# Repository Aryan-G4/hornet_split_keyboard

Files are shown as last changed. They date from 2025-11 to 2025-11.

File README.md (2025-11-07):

# Hornet Keyboard — Split Wireless Communication and Charging Mechanical Keyboard PCB

The Hornet Keyboard is the *first* fully custom, split, mechanical keyboard featuring integrated **Bluetooth**, **Qi wireless charging** on either split, and optional **USB-C programmability/Connectivity**.  
This project represents a complete end-to-end embedded hardware design — from schematic capture to multi-layer PCB layout — optimized for both performance and manufacturability.


---

## Project Overview

| Feature | Description |
|---|---|
| **Form Factor** | Compact Split ergonomic layout key matrix |
| **Microcontroller** | Industry standard NRF52840 QIAA semi-BGA |
| **MCU Interface** | USB-C (DFU bootloader + HID communication) and STLinkV3 SWD |
| **Wireless** | On-board Bluetooth LE trace antenna with matched RF trace and controlled impedance |
| **Power** | Dual power paths: 3.7 V LiPo battery or USB VBUS (5 V) with power switching (USB PRIORITY)|
| **Charging Options** | USB-C Power Delivery (5V @ 1000mA) or Qi wireless charging receiver (5V @ 800mA)|
| **Firmware** | DFU-based update over USB; designed for ZMK and QMK-style firmware structure |
| **Sensors** | On-board voltage monitoring and NTC-based battery temperature protection |
| **Other** | Rotary encoders, Jumpers to probe and enable/disable submodules | standardized M3 mounting holes |
---
## Schematics




## Layout

3D model (ish)

hornet_kb_jlcpcb_render

Individual Layers:
L1: FCu

L2: In1

L3: In2

L4: BCu


## System Architecture

The system integrates three major electrical domains:

1. **Digital Domain (nRF52840)**
   - Industry standard MCU with built-in BLE 5.4
   - High-speed interrupt-based matrix scanning and battery management.
   - Dedicated power pin for reading battery charge.

2. **Power Management Domain**
   - Dual-source power path with **ideal diode OR-ing** between USB VBUS and LiPo battery.
   - **Li-Ion charge controller** managing both USB and Qi charge inputs.
   - **Dynamic load sharing** ensures stable operation while charging.
   - **Overcurrent and thermal protection** via FET-based switching and NTC feedback.

3. **Wireless RF Domain**
   - Custom-routed **50 Ω matched trace** for the Bluetooth antenna.
   - π-matching network for impedance tuning based on antenna manufacturer data.
   - Keepout and ground clearance zone designed per RF layout guidelines.

---

## Electrical Design Highlights

- **4-layer PCB** for clean separation of signal, power, and RF planes.
- **Differential USB data routing** (D+ / D–) with 90 Ω differential impedance.
- **Common-mode choke** and ESD suppression on USB-C connector for EMI resilience.
- **Reverse-current blocking MOSFET** for power path control between USB and battery.
- **Qi receiver integration** including rectification, voltage regulation, and charge negotiation.
- **Seamless transition** between wireless power and USB without brownout.

## Tools and Workflow

- **KiCad 8.0** — schematic capture and PCB design  
- **JLCPCB / LCSC** — fabrication and component sourcing  
- **SolidWorks** — mechanical fit and case alignment  
- **ZMK** - Open source repo for wireless split keyboards
- **DFU-util** — firmware flashing over USB-C and SWD through my STLinkV3

---

## Firmware Architecture 
- Utilize USBC's DFU to flash all firmware and STLinkV3 to flash in case of USBC fail
- Implement ZMK- wireless open source keyboard firmware kit for wireless split keyboards
- Implement QMK alternatively, for wired keyboards
- Eventually write my own firmware, optimizing speed and runtime.

---

---

## Gallery and work in progress photos :D










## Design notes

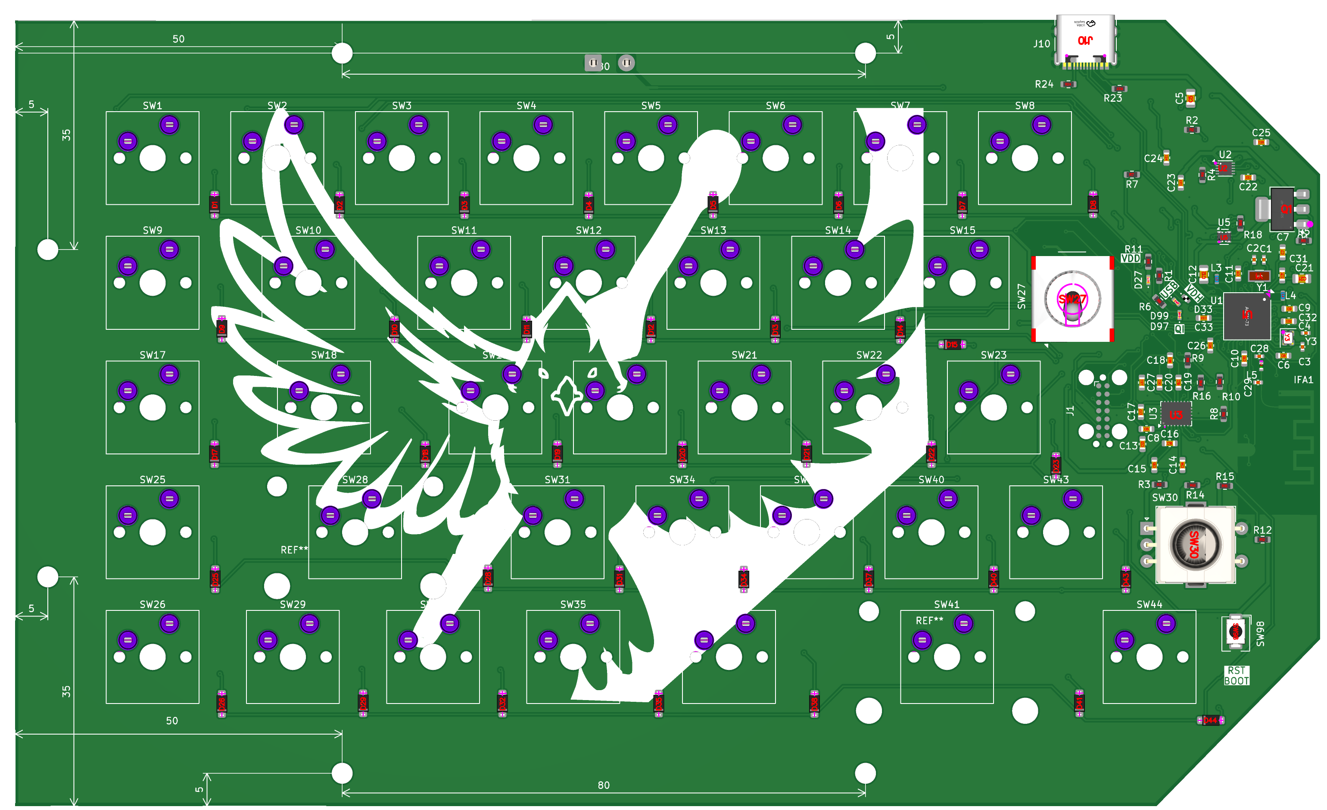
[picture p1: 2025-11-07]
hornet_kb_jlcpcb_render.png

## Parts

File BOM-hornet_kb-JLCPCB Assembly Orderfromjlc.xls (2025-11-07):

JLCPCB BOM Tool - BOM Matching
BOM name：BOM-hornet_kb-JLCPCB Assembly Order.xlsx |  |  | Download Time：2025-10-26 09:23:43 |  |  |  | * Our matching results are updated in real-time, but stock and prices may change. If it's been over 24 hours, please re-match before placing your order.
PCB Assembled Qty：5 |  |  | Est. Total Price：134.5413
Your BOM |  |  |  |  | Matched Parts |  |  |  |  |  |  | Order Information
Top Designator | Bottom Designator | Comment | Footprint | JLCPCB Part # | Matches | Part # | Manufacturer | Footprint | Description | Category | Warning | JLCPCB Part # | Product link | Lib Type | Qty | Source | Total Price ($)
C1 |  | 12p | C_0402_1005Metric |  | Select by Customer | 0402CG120J500NT | FH (Guangdong Fenghua Advanced Tech) | 0402 | 12pF 50V C0G ±5% 0402 Multilayer Ceramic Capacitors MLCC - SMD/SMT ROHS | Multilayer Ceramic Capacitors MLCC - SMD/SMT | 1.The comment (0402CG120J500NT) of this part does not match the one (12p) provided in your BOM. Please confirm; | C1547 | https://jlcpcb.com/partdetail/1899-0402CG120J500NT/C1547 | Basic | 20 | 20 JLCPCB | 0.022
C2 |  | 12p | C_0402_1005Metric |  | Select by Customer | 0402CG120J500NT | FH (Guangdong Fenghua Advanced Tech) | 0402 | 12pF 50V C0G ±5% 0402 Multilayer Ceramic Capacitors MLCC - SMD/SMT ROHS | Multilayer Ceramic Capacitors MLCC - SMD/SMT | 1.The comment (0402CG120J500NT) of this part does not match the one (12p) provided in your BOM. Please confirm; | C1547 | https://jlcpcb.com/partdetail/1899-0402CG120J500NT/C1547 | Basic | 20 | 20 JLCPCB | 0.022
C3 |  | 12p | C_0402_1005Metric |  | Select by Customer | 0402CG120J500NT | FH (Guangdong Fenghua Advanced Tech) | 0402 | 12pF 50V C0G ±5% 0402 Multilayer Ceramic Capacitors MLCC - SMD/SMT ROHS | Multilayer Ceramic Capacitors MLCC - SMD/SMT | 1.The comment (0402CG120J500NT) of this part does not match the one (12p) provided in your BOM. Please confirm; | C1547 | https://jlcpcb.com/partdetail/1899-0402CG120J500NT/C1547 | Basic | 20 | 20 JLCPCB | 0.022
C4 |  | 12p | C_0402_1005Metric |  | Select by Customer | 0402CG120J500NT | FH (Guangdong Fenghua Advanced Tech) | 0402 | 12pF 50V C0G ±5% 0402 Multilayer Ceramic Capacitors MLCC - SMD/SMT ROHS | Multilayer Ceramic Capacitors MLCC - SMD/SMT | 1.The comment (0402CG120J500NT) of this part does not match the one (12p) provided in your BOM. Please confirm; | C1547 | https://jlcpcb.com/partdetail/1899-0402CG120J500NT/C1547 | Basic | 20 | 20 JLCPCB | 0.022
C5 |  | 4.7u | C_0805_2012Metric |  | Unconfirmed | CL21A475KAQNNNE | Samsung Electro-Mechanics | 0805 | 25V 4.7uF X5R ±10% 0805 Multilayer Ceramic Capacitors MLCC - SMD/SMT ROHS | Multilayer Ceramic Capacitors MLCC - SMD/SMT | 1.The comment (CL21A475KAQNNNE) of this part does not match the one (4.7u) provided in your BOM. Please confirm; | C1779 | https://jlcpcb.com/partdetail/2131-CL21A475KAQNNNE/C1779 | Basic | 20 | 20 JLCPCB | 0.238
C12 |  | 4.7u | C_0805_2012Metric |  | Unconfirmed | CL21A475KAQNNNE | Samsung Electro-Mechanics | 0805 | 25V 4.7uF X5R ±10% 0805 Multilayer Ceramic Capacitors MLCC - SMD/SMT ROHS | Multilayer Ceramic Capacitors MLCC - SMD/SMT | 1.The comment (CL21A475KAQNNNE) of this part does not match the one (4.7u) provided in your BOM. Please confirm; | C1779 | https://jlcpcb.com/partdetail/2131-CL21A475KAQNNNE/C1779 | Basic | 20 | 20 JLCPCB | 0.238
C21 |  | 4.7u | C_0805_2012Metric |  | Unconfirmed | CL21A475KAQNNNE | Samsung Electro-Mechanics | 0805 | 25V 4.7uF X5R ±10% 0805 Multilayer Ceramic Capacitors MLCC - SMD/SMT ROHS | Multilayer Ceramic Capacitors MLCC - SMD/SMT | 1.The comment (CL21A475KAQNNNE) of this part does not match the one (4.7u) provided in your BOM. Please confirm; | C1779 | https://jlcpcb.com/partdetail/2131-CL21A475KAQNNNE/C1779 | Basic | 20 | 20 JLCPCB | 0.238
C6 |  | 100p | C_0603_1608Metric |  | Unconfirmed | CL10C101JB8NNNC | Samsung Electro-Mechanics | 0603 | 100pF 50V C0G ±5% 0603 Multilayer Ceramic Capacitors MLCC - SMD/SMT ROHS | Multilayer Ceramic Capacitors MLCC - SMD/SMT | 1.The comment (CL10C101JB8NNNC) of this part does not match the one (100p) provided in your BOM. Please confirm; | C14858 | https://jlcpcb.com/partdetail/15530-CL10C101JB8NNNC/C14858 | Basic | 24 | 24 JLCPCB | 0.0744
C8 |  | 100p | C_0603_1608Metric |  | Unconfirmed | CL10C101JB8NNNC | Samsung Electro-Mechanics | 0603 | 100pF 50V C0G ±5% 0603 Multilayer Ceramic Capacitors MLCC - SMD/SMT ROHS | Multilayer Ceramic Capacitors MLCC - SMD/SMT | 1.The comment (CL10C101JB8NNNC) of this part does not match the one (100p) provided in your BOM. Please confirm; | C14858 | https://jlcpcb.com/partdetail/15530-CL10C101JB8NNNC/C14858 | Basic | 24 | 24 JLCPCB | 0.0744
C11 |  | 100p | C_0603_1608Metric |  | Unconfirmed | CL10C101JB8NNNC | Samsung Electro-Mechanics | 0603 | 100pF 50V C0G ±5% 0603 Multilayer Ceramic Capacitors MLCC - SMD/SMT ROHS | Multilayer Ceramic Capacitors MLCC - SMD/SMT | 1.The comment (CL10C101JB8NNNC) of this part does not match the one (100p) provided in your BOM. Please confirm; | C14858 | https://jlcpcb.com/partdetail/15530-CL10C101JB8NNNC/C14858 | Basic | 24 | 24 JLCPCB | 0.0744
C26 |  | 100p | C_0603_1608Metric |  | Unconfirmed | CL10C101JB8NNNC | Samsung Electro-Mechanics | 0603 | 100pF 50V C0G ±5% 0603 Multilayer Ceramic Capacitors MLCC - SMD/SMT ROHS | Multilayer Ceramic Capacitors MLCC - SMD/SMT | 1.The comment (CL10C101JB8NNNC) of this part does not match the one (100p) provided in your BOM. Please confirm; | C14858 | https://jlcpcb.com/partdetail/15530-CL10C101JB8NNNC/C14858 | Basic | 24 | 24 JLCPCB | 0.0744
C31 |  | 100p | C_0603_1608Metric |  | Unconfirmed | CL10C101JB8NNNC | Samsung Electro-Mechanics | 0603 | 100pF 50V C0G ±5% 0603 Multilayer Ceramic Capacitors MLCC - SMD/SMT ROHS | Multilayer Ceramic Capacitors MLCC - SMD/SMT | 1.The comment (CL10C101JB8NNNC) of this part does not match the one (100p) provided in your BOM. Please confirm; | C14858 | https://jlcpcb.com/partdetail/15530-CL10C101JB8NNNC/C14858 | Basic | 24 | 24 JLCPCB | 0.0744
C32 |  | 100p | C_0603_1608Metric |  | Unconfirmed | CL10C101JB8NNNC | Samsung Electro-Mechanics | 0603 | 100pF 50V C0G ±5% 0603 Multilayer Ceramic Capacitors MLCC - SMD/SMT ROHS | Multilayer Ceramic Capacitors MLCC - SMD/SMT | 1.The comment (CL10C101JB8NNNC) of this part does not match the one (100p) provided in your BOM. Please confirm; | C14858 | https://jlcpcb.com/partdetail/15530-CL10C101JB8NNNC/C14858 | Basic | 24 | 24 JLCPCB | 0.0744
C33 |  | 100p | C_0603_1608Metric |  | Unconfirmed | CL10C101JB8NNNC | Samsung Electro-Mechanics | 0603 | 100pF 50V C0G ±5% 0603 Multilayer Ceramic Capacitors MLCC - SMD/SMT ROHS | Multilayer Ceramic Capacitors MLCC - SMD/SMT | 1.The comment (CL10C101JB8NNNC) of this part does not match the one (100p) provided in your BOM. Please confirm; | C14858 | https://jlcpcb.com/partdetail/15530-CL10C101JB8NNNC/C14858 | Basic | 24 | 24 JLCPCB | 0.0744
C7 |  | 100n | C_0603_1608Metric |  | Unconfirmed | CC0603KRX7R9BB104 | YAGEO | 0603 | 100nF 50V X7R ±10% 0603 Multilayer Ceramic Capacitors MLCC - SMD/SMT ROHS | Multilayer Ceramic Capacitors MLCC - SMD/SMT | 1.The comment (CC0603KRX7R9BB104) of this part does not match the one (100n) provided in your BOM. Please confirm; | C14663 | https://jlcpcb.com/partdetail/YAGEO-CC0603KRX7R9BB104/C14663 | Basic | 20 | 20 JLCPCB | 0.048
C9 |  | 1u | C_0603_1608Metric |  | Unconfirmed | CL10A105KB8NNNC | Samsung Electro-Mechanics | 0603 | 1uF 50V X5R ±10% 0603 Multilayer Ceramic Capacitors MLCC - SMD/SMT ROHS | Multilayer Ceramic Capacitors MLCC - SMD/SMT | 1.The comment (CL10A105KB8NNNC) of this part does not match the one (1u) provided in your BOM. Please confirm; | C15849 | https://jlcpcb.com/partdetail/16531-CL10A105KB8NNNC/C15849 | Basic | 20 | 20 JLCPCB | 0.094
C22 |  | 1u | C_0603_1608Metric |  | Unconfirmed | CL10A105KB8NNNC | Samsung Electro-Mechanics | 0603 | 1uF 50V X5R ±10% 0603 Multilayer Ceramic Capacitors MLCC - SMD/SMT ROHS | Multilayer Ceramic Capacitors MLCC - SMD/SMT | 1.The comment (CL10A105KB8NNNC) of this part does not match the one (1u) provided in your BOM. Please confirm; | C15849 | https://jlcpcb.com/partdetail/16531-CL10A105KB8NNNC/C15849 | Basic | 20 | 20 JLCPCB | 0.094
C23 |  | 1u | C_0603_1608Metric |  | Unconfirmed | CL10A105KB8NNNC | Samsung Electro-Mechanics | 0603 | 1uF 50V X5R ±10% 0603 Multilayer Ceramic Capacitors MLCC - SMD/SMT ROHS | Multilayer Ceramic Capacitors MLCC - SMD/SMT | 1.The comment (CL10A105KB8NNNC) of this part does not match the one (1u) provided in your BOM. Please confirm; | C15849 | https://jlcpcb.com/partdetail/16531-CL10A105KB8NNNC/C15849 | Basic | 20 | 20 JLCPCB | 0.094
C10 |  | 820p | C_0603_1608Metric |  | Unconfirmed | CC0603JRNPO9BN821 | YAGEO | 0603 | 50V 820pF NP0 ±5% 0603 Multilayer Ceramic Capacitors MLCC - SMD/SMT ROHS | Multilayer Ceramic Capacitors MLCC - SMD/SMT | 1.The comment (CC0603JRNPO9BN821) of this part does not match the one (820p) provided in your BOM. Please confirm; | C107057 | https://jlcpcb.com/partdetail/YAGEO-CC0603JRNPO9BN821/C107057 | Extended | 20 | 20 JLCPCB | 0.082
C13 |  | 200n | C_0603_1608Metric |  | Select by Customer | GZ1608D601TF | Sunlord | 0603 | -55℃~+125℃ 1 200mA 450mΩ 600Ω@100MHz ±25% 0603 Ferrite Beads ROHS | Ferrite Beads | 1.The comment (GZ1608D601TF) of this part does not match the one (200n) provided in your BOM. Please confirm; | C1002 | https://jlcpcb.com/partdetail/Sunlord-GZ1608D601TF/C1002 | Basic | 20 | 20 JLCPCB | 0.132
C14 |  | 22n | C_0603_1608Metric |  | Unconfirmed | CL10B223KB8NNNC | Samsung Electro-Mechanics | 0603 | 22nF 50V X7R ±10% 0603 Multilayer Ceramic Capacitors MLCC - SMD/SMT ROHS | Multilayer Ceramic Capacitors MLCC - SMD/SMT | 1.The comment (CL10B223KB8NNNC) of this part does not match the one (22n) provided in your BOM. Please confirm; | C21122 | https://jlcpcb.com/partdetail/21834-CL10B223KB8NNNC/C21122 | Basic | 20 | 20 JLCPCB | 0.078
C19 |  | 22n | C_0603_1608Metric |  | Unconfirmed | CL10B223KB8NNNC | Samsung Electro-Mechanics | 0603 | 22nF 50V X7R ±10% 0603 Multilayer Ceramic Capacitors MLCC - SMD/SMT ROHS | Multilayer Ceramic Capacitors MLCC - SMD/SMT | 1.The comment (CL10B223KB8NNNC) of this part does not match the one (22n) provided in your BOM. Please confirm; | C21122 | https://jlcpcb.com/partdetail/21834-CL10B223KB8NNNC/C21122 | Basic | 20 | 20 JLCPCB | 0.078
C15 |  | 10n | C_0603_1608Metric |  | Unconfirmed | 0603B103K500NT | FH (Guangdong Fenghua Advanced Tech) | 0603 | 10nF 50V X7R ±10% 0603 Multilayer Ceramic Capacitors MLCC - SMD/SMT ROHS | Multilayer Ceramic Capacitors MLCC - SMD/SMT | 1.The comment (0603B103K500NT) of this part does not match the one (10n) provided in your BOM. Please confirm; | C57112 | https://jlcpcb.com/partdetail/58143-0603B103K500NT/C57112 | Basic | 20 | 20 JLCPCB | 0.048
C20 |  | 10n | C_0603_1608Metric |  | Unconfirmed | 0603B103K500NT | FH (Guangdong Fenghua Advanced Tech) | 0603 | 10nF 50V X7R ±10% 0603 Multilayer Ceramic Capacitors MLCC - SMD/SMT ROHS | Multilayer Ceramic Capacitors MLCC - SMD/SMT | 1.The comment (0603B103K500NT) of this part does not match the one (10n) provided in your BOM. Please confirm; | C57112 | https://jlcpcb.com/partdetail/58143-0603B103K500NT/C57112 | Basic | 20 | 20 JLCPCB | 0.048
C16 |  | 470p | C_0603_1608Metric |  | Unconfirmed | 0603B471K500NT | FH (Guangdong Fenghua Advanced Tech) | 0603 | 470pF 50V X7R ±10% 0603 Multilayer Ceramic Capacitors MLCC - SMD/SMT ROHS | Multilayer Ceramic Capacitors MLCC - SMD/SMT | 1.The comment (0603B471K500NT) of this part does not match the one (470p) provided in your BOM. Please confirm; | C1620 | https://jlcpcb.com/partdetail/1972-0603B471K500NT/C1620 | Basic | 20 | 20 JLCPCB | 0.054
C18 |  | 470p | C_0603_1608Metric |  | Unconfirmed | 0603B471K500NT | FH (Guangdong Fenghua Advanced Tech) | 0603 | 470pF 50V X7R ±10% 0603 Multilayer Ceramic Capacitors MLCC - SMD/SMT ROHS | Multilayer Ceramic Capacitors MLCC - SMD/SMT | 1.The comment (0603B471K500NT) of this part does not match the one (470p) provided in your BOM. Please confirm; | C1620 | https://jlcpcb.com/partdetail/1972-0603B471K500NT/C1620 | Basic | 20 | 20 JLCPCB | 0.054
C17 |  | 2.2n | C_0603_1608Metric |  | Unconfirmed | 0603B222K500NT | FH (Guangdong Fenghua Advanced Tech) | 0603 | 2.2nF 50V X7R ±10% 0603 Multilayer Ceramic Capacitors MLCC - SMD/SMT ROHS | Multilayer Ceramic Capacitors MLCC - SMD/SMT | 1.The comment (0603B222K500NT) of this part does not match the one (2.2n) provided in your BOM. Please confirm; | C1604 | https://jlcpcb.com/partdetail/1956-0603B222K500NT/C1604 | Basic | 20 | 20 JLCPCB | 0.054
C24 |  | 10u | C_0603_1608Metric |  | Unconfirmed | CL10A106KP8NNNC | Samsung Electro-Mechanics | 0603 | 10V 10uF X5R ±10% 0603 Multilayer Ceramic Capacitors MLCC - SMD/SMT ROHS | Multilayer Ceramic Capacitors MLCC - SMD/SMT | 1.The comment (CL10A106KP8NNNC) of this part does not match the one (10u) provided in your BOM. Please confirm; | C19702 | https://jlcpcb.com/partdetail/20411-CL10A106KP8NNNC/C19702 | Basic | 20 | 20 JLCPCB | 0.112
C25 |  | 10u | C_0603_1608Metric |  | Unconfirmed | CL10A106KP8NNNC | Samsung Electro-Mechanics | 0603 | 10V 10uF X5R ±10% 0603 Multilayer Ceramic Capacitors MLCC - SMD/SMT ROHS | Multilayer Ceramic Capacitors MLCC - SMD/SMT | 1.The comment (CL10A106KP8NNNC) of this part does not match the one (10u) provided in your BOM. Please confirm; | C19702 | https://jlcpcb.com/partdetail/20411-CL10A106KP8NNNC/C19702 | Basic | 20 | 20 JLCPCB | 0.112
C27 |  | 4.7u | C_0603_1608Metric |  | Unconfirmed | CL10A475KO8NNNC | Samsung Electro-Mechanics | 0603 | 16V 4.7uF X5R ±10% 0603 Multilayer Ceramic Capacitors MLCC - SMD/SMT ROHS | Multilayer Ceramic Capacitors MLCC - SMD/SMT | 1.The comment (CL10A475KO8NNNC) of this part does not match the one (4.7u) provided in your BOM. Please confirm; | C19666 | https://jlcpcb.com/partdetail/20375-CL10A475KO8NNNC/C19666 | Basic | 20 | 20 JLCPCB | 0.184
C28 |  | 1p | C_0402_1005Metric |  | Select by Customer | 0402CG1R0C500NT | FH (Guangdong Fenghua Advanced Tech) | 0402 | 1pF 50V C0G 0402 Multilayer Ceramic Capacitors MLCC - SMD/SMT ROHS | Multilayer Ceramic Capacitors MLCC - SMD/SMT | 1.The comment (0402CG1R0C500NT) of this part does not match the one (1p) provided in your BOM. Please confirm; | C1550 | https://jlcpcb.com/partdetail/1902-0402CG1R0C500NT/C1550 | Extended | 20 | 20 JLCPCB | 0.022
C29 |  | 1p | C_0402_1005Metric |  | Select by Customer | 0402CG1R0C500NT | FH (Guangdong Fenghua Advanced Tech) | 0402 | 1pF 50V C0G 0402 Multilayer Ceramic Capacitors MLCC - SMD/SMT ROHS | Multilayer Ceramic Capacitors MLCC - SMD/SMT | 1.The comment (0402CG1R0C500NT) of this part does not match the one (1p) provided in your BOM. Please confirm; | C1550 | https://jlcpcb.com/partdetail/1902-0402CG1R0C500NT/C1550 | Extended | 20 | 20 JLCPCB | 0.022
D1 |  | ESC | Diode_SOD-123 |  | Unconfirmed | 1N4148W | JSMSEMI | SOD-123 | -55℃~+150℃@(Tj) 1.25V@150mA 100V 1uA@75V 300mA 400mW 4A 8ns Independent SOD-123 Switching Diodes ROHS | Switching Diodes | 1.Multiple lines in the BOM have been matched to the same part. Please check if the matching is correct. ; | C917030 | https://jlcpcb.com/partdetail/JSMSEMI-1N4148W/C917030 | Extended | 84 | 84 JLCPCB | 0.4452
D2 |  | ~/` | Diode_SOD-123 |  | Unconfirmed | 1N4148W | JSMSEMI | SOD-123 | -55℃~+150℃@(Tj) 1.25V@150mA 100V 1uA@75V 300mA 400mW 4A 8ns Independent SOD-123 Switching Diodes ROHS | Switching Diodes | 1.Multiple lines in the BOM have been matched to the same part. Please check if the matching is correct. ; | C917030 | https://jlcpcb.com/partdetail/JSMSEMI-1N4148W/C917030 | Extended | 84 | 84 JLCPCB | 0.4452
D3 |  | 1 | Diode_SOD-123 |  | Unconfirmed | 1N4148W | JSMSEMI | SOD-123 | -55℃~+150℃@(Tj) 1.25V@150mA 100V 1uA@75V 300mA 400mW 4A 8ns Independent SOD-123 Switching Diodes ROHS | Switching Diodes | 1.Multiple lines in the BOM have been matched to the same part. Please check if the matching is correct. ; | C917030 | https://jlcpcb.com/partdetail/JSMSEMI-1N4148W/C917030 | Extended | 84 | 84 JLCPCB | 0.4452
D4 |  | 2 | Diode_SOD-123 |  | Unconfirmed | 1N4148W | JSMSEMI | SOD-123 | -55℃~+150℃@(Tj) 1.25V@150mA 100V 1uA@75V 300mA 400mW 4A 8ns Independent SOD-123 Switching Diodes ROHS | Switching Diodes | 1.Multiple lines in the BOM have been matched to the same part. Please check if the matching is correct. ; | C917030 | https://jlcpcb.com/partdetail/JSMSEMI-1N4148W/C917030 | Extended | 84 | 84 JLCPCB | 0.4452
D5 |  | 3 | Diode_SOD-123 |  | Unconfirmed | 1N4148W | JSMSEMI | SOD-123 | -55℃~+150℃@(Tj) 1.25V@150mA 100V 1uA@75V 300mA 400mW 4A 8ns Independent SOD-123 Switching Diodes ROHS | Switching Diodes | 1.Multiple lines in the BOM have been matched to the same part. Please check if the matching is correct. ; | C917030 | https://jlcpcb.com/partdetail/JSMSEMI-1N4148W/C917030 | Extended | 84 | 84 JLCPCB | 0.4452
D6 |  | 4 | Diode_SOD-123 |  | Unconfirmed | 1N4148W | JSMSEMI | SOD-123 | -55℃~+150℃@(Tj) 1.25V@150mA 100V 1uA@75V 300mA 400mW 4A 8ns Independent SOD-123 Switching Diodes ROHS | Switching Diodes | 1.Multiple lines in the BOM have been matched to the same part. Please check if the matching is correct. ; | C917030 | https://jlcpcb.com/partdetail/JSMSEMI-1N4148W/C917030 | Extended | 84 | 84 JLCPCB | 0.4452
D7 |  | 5 | Diode_SOD-123 |  | Unconfirmed | 1N4148W | JSMSEMI | SOD-123 | -55℃~+150℃@(Tj) 1.25V@150mA 100V 1uA@75V 300mA 400mW 4A 8ns Independent SOD-123 Switching Diodes ROHS | Switching Diodes | 1.Multiple lines in the BOM have been matched to the same part. Please check if the matching is correct. ; | C917030 | https://jlcpcb.com/partdetail/JSMSEMI-1N4148W/C917030 | Extended | 84 | 84 JLCPCB | 0.4452
D8 |  | 6 | Diode_SOD-123 |  | Unconfirmed | 1N4148W | JSMSEMI | SOD-123 | -55℃~+150℃@(Tj) 1.25V@150mA 100V 1uA@75V 300mA 400mW 4A 8ns Independent SOD-123 Switching Diodes ROHS | Switching Diodes | 1.Multiple lines in the BOM have been matched to the same part. Please check if the matching is correct. ; | C917030 | https://jlcpcb.com/partdetail/JSMSEMI-1N4148W/C917030 | Extended | 84 | 84 JLCPCB | 0.4452
D10,D11,D12,D13,D14,D15,D17,D18,D19,D20,D21,D22,D23,D25,D26,D28,D29,D31,D32,D34,D35,D37,D38,D40,D41,D43,D44,D9 |  | D | Diode_SOD-123 |  | Unconfirmed | 1N4148W | JSMSEMI | SOD-123 | -55℃~+150℃@(Tj) 1.25V@150mA 100V 1uA@75V 300mA 400mW 4A 8ns Independent SOD-123 Switching Diodes ROHS | Switching Diodes | 1.Multiple lines in the BOM have been matched to the same part. Please check if the matching is correct. ; | C917030 | https://jlcpcb.com/partdetail/JSMSEMI-1N4148W/C917030 | Extended | 84 | 84 JLCPCB | 0.4452
D27 |  | VDD | LED_0402_1005Metric |  | Select by System | YLED0402B | YONGYUTAI | 0402 | -40℃~+85℃ 100mW 100mcd 120° 2.6V~3.1V 20mA 460nm~475nm 469nm Blue Water Clear 0402 LED Indication - Discrete ROHS | LED Indication - Discrete |  | C30584803 | https://jlcpcb.com/partdetail/YONGYUTAI-YLED0402B/C30584803 | Extended | 20 | 20 JLCPCB | 0.252
D33 |  | LED | LED_0402_1005Metric |  | Select by Customer | YLED0402O | YONGYUTAI | 0402 | -40℃~+85℃ 1.8V~2.3V 120° 20mA 210mcd 48mW 598nm~608nm 611nm Orange Water Clear 0402 LED Indication - Discrete ROHS | LED Indication - Discrete | 1.The comment (YLED0402O) of this part does not match the one (LED) provided in your BOM. Please confirm; | C28310436 | https://jlcpcb.com/partdetail/YONGYUTAI-YLED0402O/C28310436 | Extended | 20 | 20 JLCPCB | 0.152
D97 |  | USB_CHG | LED_0402_1005Metric |  | Select by Customer | 16-213SDRC/S530-A3/TR8 | Everlight Elec | 0402 | 120° 20mA 2V 43mcd 639nm 650nm Red Water Clear 0402 LED Indication - Discrete ROHS | LED Indication - Discrete |  | C71911 | https://jlcpcb.com/partdetail/EverlightElec-16_213SDRC_S530_A3TR8/C71911 | Extended | 7 | 7 JLCPCB | 0.2114
D99 |  | QI_CHG | LED_0402_1005Metric |  | Select by Customer | 16-213/GHC-YR1S1/3T | Everlight Elec | 0402 | -40℃~+85℃ 110mW 120° 20mA 518nm 520nm~535nm Emerald Green Water Clear 0402 LED Indication - Discrete ROHS | LED Indication - Discrete |  | C74338 | https://jlcpcb.com/partdetail/EverlightElec-16_213_GHC_YR1S13T/C74338 | Extended | 7 | 7 JLCPCB | 0.3486
 | J2 | Conn_01x03 | JST_GH_SM03B-GHS-TB_1x03-1MP_P1.25mm_Horizontal |  | Select by System | SM03B-GHS-TB(LF)(SN) | JST | SMD,P=1.25mm,卧贴 | -25℃~+85℃ 1 1.25mm 1A 1x3P 3 3P 4.13mm 4.25mm 50V 7mm Auxiliary Solder Pin GH PA9T Phosphor Bronze Surface Mount, Right Angle Tin UL94V-0 White SMD,P=1.25mm,Surface Mount，Right Angle Wire To Board Connector ROHS | Wire To Board Connector |  | C514175 | https://jlcpcb.com/partdetail/JST-SM03B_GHS_TB_LF_SN/C514175 | Extended | 5 | 5 JLCPCB | 0.597
J10 |  | USB_C_Receptacle_USB2.0 | USB_C_Receptacle_HRO_TYPE-C-31-M-12 |  | Select by System | TYPE-C-31-M-12 | Korean Hroparts Elec | SMD | 1 16P 5A Female Type-C SMD USB Connectors ROHS | USB Connectors |  | C165948 | https://jlcpcb.com/partdetail/Korean_HropartsElec-TYPE_C_31_M12/C165948 | Extended | 2 | 2 JLCPCB | 0.3388
 | L1 | 6.3u | TerminalBlock_Phoenix_MKDS-1,5-2-5.08_1x02_P5.08mm_Horizontal |  | Select by System | WJ500V-5.08-2P | Ningbo Kangnex Elec | 插件,P=5.08mm | -40℃~+105℃ 1 14~30 18A 1x2P 2 2.5 250V 2P 5.08mm Green M2.5 Through Hole Plugin,P=5.08mm Screw Terminal Blocks ROHS | Screw Terminal Blocks |  | C8465 | https://jlcpcb.com/partdetail/Ningbo_KangnexElec-WJ500V_5_082P/C8465 | Extended | 2 | 2 JLCPCB | 0.213
L3 |  | 10u | L_0402_1005Metric |  | Unconfirmed | PSPMAA0402-100M-ANP | PROD Tech | SMD,4.5x4.1mm | 1.2A 10uH 2.2A 282mΩ ±20% SMD,4.5x4.1mm Power Inductors ROHS | Power Inductors | 1.The comment (PSPMAA0402-100M-ANP) of this part does not match the one (10u) provided in your BOM. Please confirm; | C436512 | https://jlcpcb.com/partdetail/PRODTech-PSPMAA0402_100MANP/C436512 | Extended | 5 | 5 JLCPCB | 0.6825
L4 |  | 25u | L_0402_1005Metric |  | Select by Customer | LQG15HS27NJ02D | Murata Electronics | 0402 | 1.7GHz 27nH 350mA 460mΩ 8@100MHz ±5% 0402 Inductors (SMD) ROHS | Inductors (SMD) |  | C12669 | https://jlcpcb.com/partdetail/MurataElectronics-LQG15HS27NJ02D/C12669 | Extended | 20 | 20 JLCPCB | 0.124
L5 |  | 4.7n | L_0402_1005Metric |  | Unconfirmed | LQG15HS4N7S02D | Murata Electronics | 0402 | 160mΩ 4.7nH 6GHz 700mA 8@100MHz 0402 Inductors (SMD) ROHS | Inductors (SMD) | 1.The comment (LQG15HS4N7S02D) of this part does not match the one (4.7n) provided in your BOM. Please confirm; | C86065 | https://jlcpcb.com/partdetail/MurataElectronics-LQG15HS4N7S02D/C86065 | Extended | 20 | 20 JLCPCB | 0.148
Q1 |  | BTS4140N | SOT-223 |  | Select by System | BTS4140N | Infineon Technologies | SOT-223 | -40℃~+150℃ 1 1Ω 4.9V~60V Active Low High Side Switch Short-Circuit Protection(SCP) SOT-223 Power Distribution Switches ROHS | Power Distribution Switches |  | C59442 | https://jlcpcb.com/partdetail/InfineonTechnologies-BTS4140N/C59442 | Extended | 2 | 2 JLCPCB | 1.515
R1 |  | 500 | R_0603_1608Metric |  | Unconfirmed | RT0603BRD07500RL | YAGEO | 0603 | -55℃~+155℃ 100mW 500Ω Thin Film Resistor ±0.1% ±25ppm/℃ 0603 Chip Resistor - Surface Mount ROHS | Chip Resistor - Surface Mount | 1.The comment (RT0603BRD07500RL) of this part does not match the one (500) provided in your BOM. Please confirm; | C6207671 | https://jlcpcb.com/partdetail/YAGEO-RT0603BRD07500RL/C6207671 | Extended | 20 | 20 JLCPCB | 0.45
R6 |  | 500 | R_0603_1608Metric |  | Unconfirmed | RT0603BRD07500RL | YAGEO | 0603 | -55℃~+155℃ 100mW 500Ω Thin Film Resistor ±0.1% ±25ppm/℃ 0603 Chip Resistor - Surface Mount ROHS | Chip Resistor - Surface Mount | 1.The comment (RT0603BRD07500RL) of this part does not match the one (500) provided in your BOM. Please confirm; | C6207671 | https://jlcpcb.com/partdetail/YAGEO-RT0603BRD07500RL/C6207671 | Extended | 20 | 20 JLCPCB | 0.45
R11 |  | 500 | R_0603_1608Metric |  | Unconfirmed | RT0603BRD07500RL | YAGEO | 0603 | -55℃~+155℃ 100mW 500Ω Thin Film Resistor ±0.1% ±25ppm/℃ 0603 Chip Resistor - Surface Mount ROHS | Chip Resistor - Surface Mount | 1.The comment (RT0603BRD07500RL) of this part does not match the one (500) provided in your BOM. Please confirm; | C6207671 | https://jlcpcb.com/partdetail/YAGEO-RT0603BRD07500RL/C6207671 | Extended | 20 | 20 JLCPCB | 0.45
R2 |  | 1k | R_0603_1608Metric |  | Unconfirmed | 0603WAF1001T5E | UNI-ROYAL(Uniroyal Elec) | 0603 | -55℃~+155℃ 100mW 1kΩ 75V Thick Film Resistor ±1% ±100ppm/℃ 0603 Chip Resistor - Surface Mount ROHS | Chip Resistor - Surface Mount | 1.The comment (0603WAF1001T5E) of this part does not match the one (1k) provided in your BOM. Please confirm; | C21190 | https://jlcpcb.com/partdetail/21904-0603WAF1001T5E/C21190 | Basic | 20 | 20 JLCPCB | 0.02
R18 |  | 1k | R_0603_1608Metric |  | Unconfirmed | 0603WAF1001T5E | UNI-ROYAL(Uniroyal Elec) | 0603 | -55℃~+155℃ 100mW 1kΩ 75V Thick Film Resistor ±1% ±100ppm/℃ 0603 Chip Resistor - Surface Mount ROHS | Chip Resistor - Surface Mount | 1.The comment (0603WAF1001T5E) of this part does not match the one (1k) provided in your BOM. Please confirm; | C21190 | https://jlcpcb.com/partdetail/21904-0603WAF1001T5E/C21190 | Basic | 20 | 20 JLCPCB | 0.02
R3 |  | 10k | R_0603_1608Metric |  | Select by System | 0603WAF1002T5E | UNI-ROYAL(Uniroyal Elec) | 0603 | -55℃~+155℃ 100mW 10kΩ 75V Thick Film Resistor ±1% ±100ppm/℃ 0603 Chip Resistor - Surface Mount ROHS | Chip Resistor - Surface Mount |  | C25804 | https://jlcpcb.com/partdetail/26547-0603WAF1002T5E/C25804 | Basic | 22 | 22 JLCPCB | 0.0198
R5 |  | 10k | R_0603_1608Metric |  | Select by System | 0603WAF1002T5E | UNI-ROYAL(Uniroyal Elec) | 0603 | -55℃~+155℃ 100mW 10kΩ 75V Thick Film Resistor ±1% ±100ppm/℃ 0603 Chip Resistor - Surface Mount ROHS | Chip Resistor - Surface Mount |  | C25804 | https://jlcpcb.com/partdetail/26547-0603WAF1002T5E/C25804 | Basic | 22 | 22 JLCPCB | 0.0198
R9 |  | 10k | R_0603_1608Metric |  | Select by System | 0603WAF1002T5E | UNI-ROYAL(Uniroyal Elec) | 0603 | -55℃~+155℃ 100mW 10kΩ 75V Thick Film Resistor ±1% ±100ppm/℃ 0603 Chip Resistor - Surface Mount ROHS | Chip Resistor - Surface Mount |  | C25804 | https://jlcpcb.com/partdetail/26547-0603WAF1002T5E/C25804 | Basic | 22 | 22 JLCPCB | 0.0198
R12 |  | 10k | R_0603_1608Metric |  | Select by System | 0603WAF1002T5E | UNI-ROYAL(Uniroyal Elec) | 0603 | -55℃~+155℃ 100mW 10kΩ 75V Thick Film Resistor ±1% ±100ppm/℃ 0603 Chip Resistor - Surface Mount ROHS | Chip Resistor - Surface Mount |  | C25804 | https://jlcpcb.com/partdetail/26547-0603WAF1002T5E/C25804 | Basic | 22 | 22 JLCPCB | 0.0198
R14 |  | 10k | R_0603_1608Metric |  | Select by System | 0603WAF1002T5E | UNI-ROYAL(Uniroyal Elec) | 0603 | -55℃~+155℃ 100mW 10kΩ 75V Thick Film Resistor ±1% ±100ppm/℃ 0603 Chip Resistor - Surface Mount ROHS | Chip Resistor - Surface Mount |  | C25804 | https://jlcpcb.com/partdetail/26547-0603WAF1002T5E/C25804 | Basic | 22 | 22 JLCPCB | 0.0198
R15 |  | 10k | R_0603_1608Metric |  | Select by System | 0603WAF1002T5E | UNI-ROYAL(Uniroyal Elec) | 0603 | -55℃~+155℃ 100mW 10kΩ 75V Thick Film Resistor ±1% ±100ppm/℃ 0603 Chip Resistor - Surface Mount ROHS | Chip Resistor - Surface Mount |  | C25804 | https://jlcpcb.com/partdetail/26547-0603WAF1002T5E/C25804 | Basic | 22 | 22 JLCPCB | 0.0198
R4 |  | 2k | R_0603_1608Metric |  | Unconfirmed | 0603WAF2001T5E | UNI-ROYAL(Uniroyal Elec) | 0603 | -55℃~+155℃ 100mW 2kΩ 75V Thick Film Resistor ±1% ±100ppm/℃ 0603 Chip Resistor - Surface Mount ROHS | Chip Resistor - Surface Mount | 1.The comment (0603WAF2001T5E) of this part does not match the one (2k) provided in your BOM. Please confirm; | C22975 | https://jlcpcb.com/partdetail/23702-0603WAF2001T5E/C22975 | Basic | 20 | 20 JLCPCB | 0.02
R7 |  | 1.5k | R_0603_1608Metric |  | Unconfirmed | 0603WAF1501T5E | UNI-ROYAL(Uniroyal Elec) | 0603 | -55℃~+155℃ 1.5kΩ 100mW 75V Thick Film Resistor ±1% ±100ppm/℃ 0603 Chip Resistor - Surface Mount ROHS | Chip Resistor - Surface Mount | 1.The comment (0603WAF1501T5E) of this part does not match the one (1.5k) provided in your BOM. Please confirm; | C22843 | https://jlcpcb.com/partdetail/23570-0603WAF1501T5E/C22843 | Basic | 20 | 20 JLCPCB | 0.022
R8 |  | 2.4k | R_0603_1608Metric |  | Unconfirmed | 0603WAF2401T5E | UNI-ROYAL(Uniroyal Elec) | 0603 | -55℃~+155℃ 100mW 2.4kΩ 75V Thick Film Resistor ±1% ±100ppm/℃ 0603 Chip Resistor - Surface Mount ROHS | Chip Resistor - Surface Mount | 1.The comment (0603WAF2401T5E) of this part does not match the one (2.4k) provided in your BOM. Please confirm; | C22940 | https://jlcpcb.com/partdetail/23667-0603WAF2401T5E/C22940 | Basic | 20 | 20 JLCPCB | 0.022
R10 |  | 200 | R_0603_1608Metric |  | Unconfirmed | 0603WAF2000T5E | UNI-ROYAL(Uniroyal Elec) | 0603 | -55℃~+155℃ 100mW 200Ω 75V Thick Film Resistor ±1% ±100ppm/℃ 0603 Chip Resistor - Surface Mount ROHS | Chip Resistor - Surface Mount | 1.The comment (0603WAF2000T5E) of this part does not match the one (200) provided in your BOM. Please confirm; | C8218 | https://jlcpcb.com/partdetail/8708-0603WAF2000T5E/C8218 | Basic | 20 | 20 JLCPCB | 0.022
R16 |  | 200 | R_0603_1608Metric |  | Unconfirmed | 0603WAF2000T5E | UNI-ROYAL(Uniroyal Elec) | 0603 | -55℃~+155℃ 100mW 200Ω 75V Thick Film Resistor ±1% ±100ppm/℃ 0603 Chip Resistor - Surface Mount ROHS | Chip Resistor - Surface Mount | 1.The comment (0603WAF2000T5E) of this part does not match the one (200) provided in your BOM. Please confirm; | C8218 | https://jlcpcb.com/partdetail/8708-0603WAF2000T5E/C8218 | Basic | 20 | 20 JLCPCB | 0.022
R23 |  | 5.1K | R_0603_1608Metric |  | Unconfirmed | 0603WAF5101T5E | UNI-ROYAL(Uniroyal Elec) | 0603 | -55℃~+155℃ 100mW 5.1kΩ 75V Thick Film Resistor ±1% ±100ppm/℃ 0603 Chip Resistor - Surface Mount ROHS | Chip Resistor - Surface Mount | 1.The comment (0603WAF5101T5E) of this part does not match the one (5.1K) provided in your BOM. Please confirm; | C23186 | https://jlcpcb.com/partdetail/23913-0603WAF5101T5E/C23186 | Basic | 20 | 20 JLCPCB | 0.022
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

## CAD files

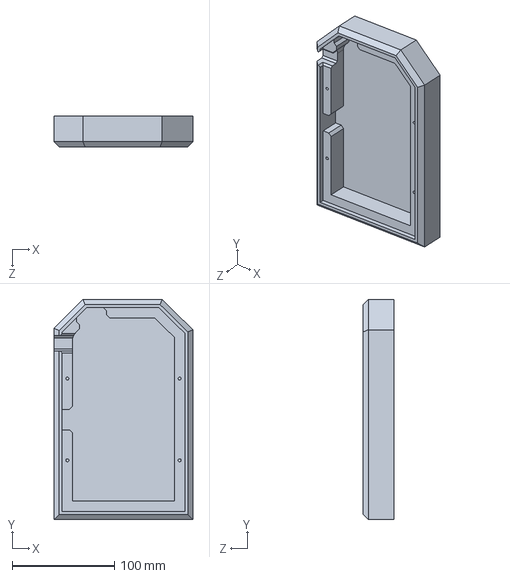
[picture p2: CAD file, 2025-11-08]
Mechanical/CaseV1.SLDPRT
136.0 x 215.5 x 30.0 mm

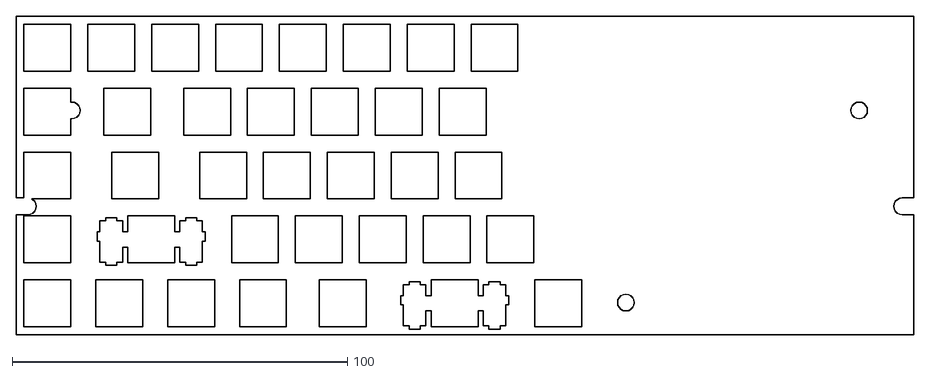
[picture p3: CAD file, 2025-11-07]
Mechanical/SwitchPlate_RAW.dxf
267.8 x 94.9

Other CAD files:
Mechanical/Plate_v1.SLDPRT
Mechanical/CaseV1_print1.STEP

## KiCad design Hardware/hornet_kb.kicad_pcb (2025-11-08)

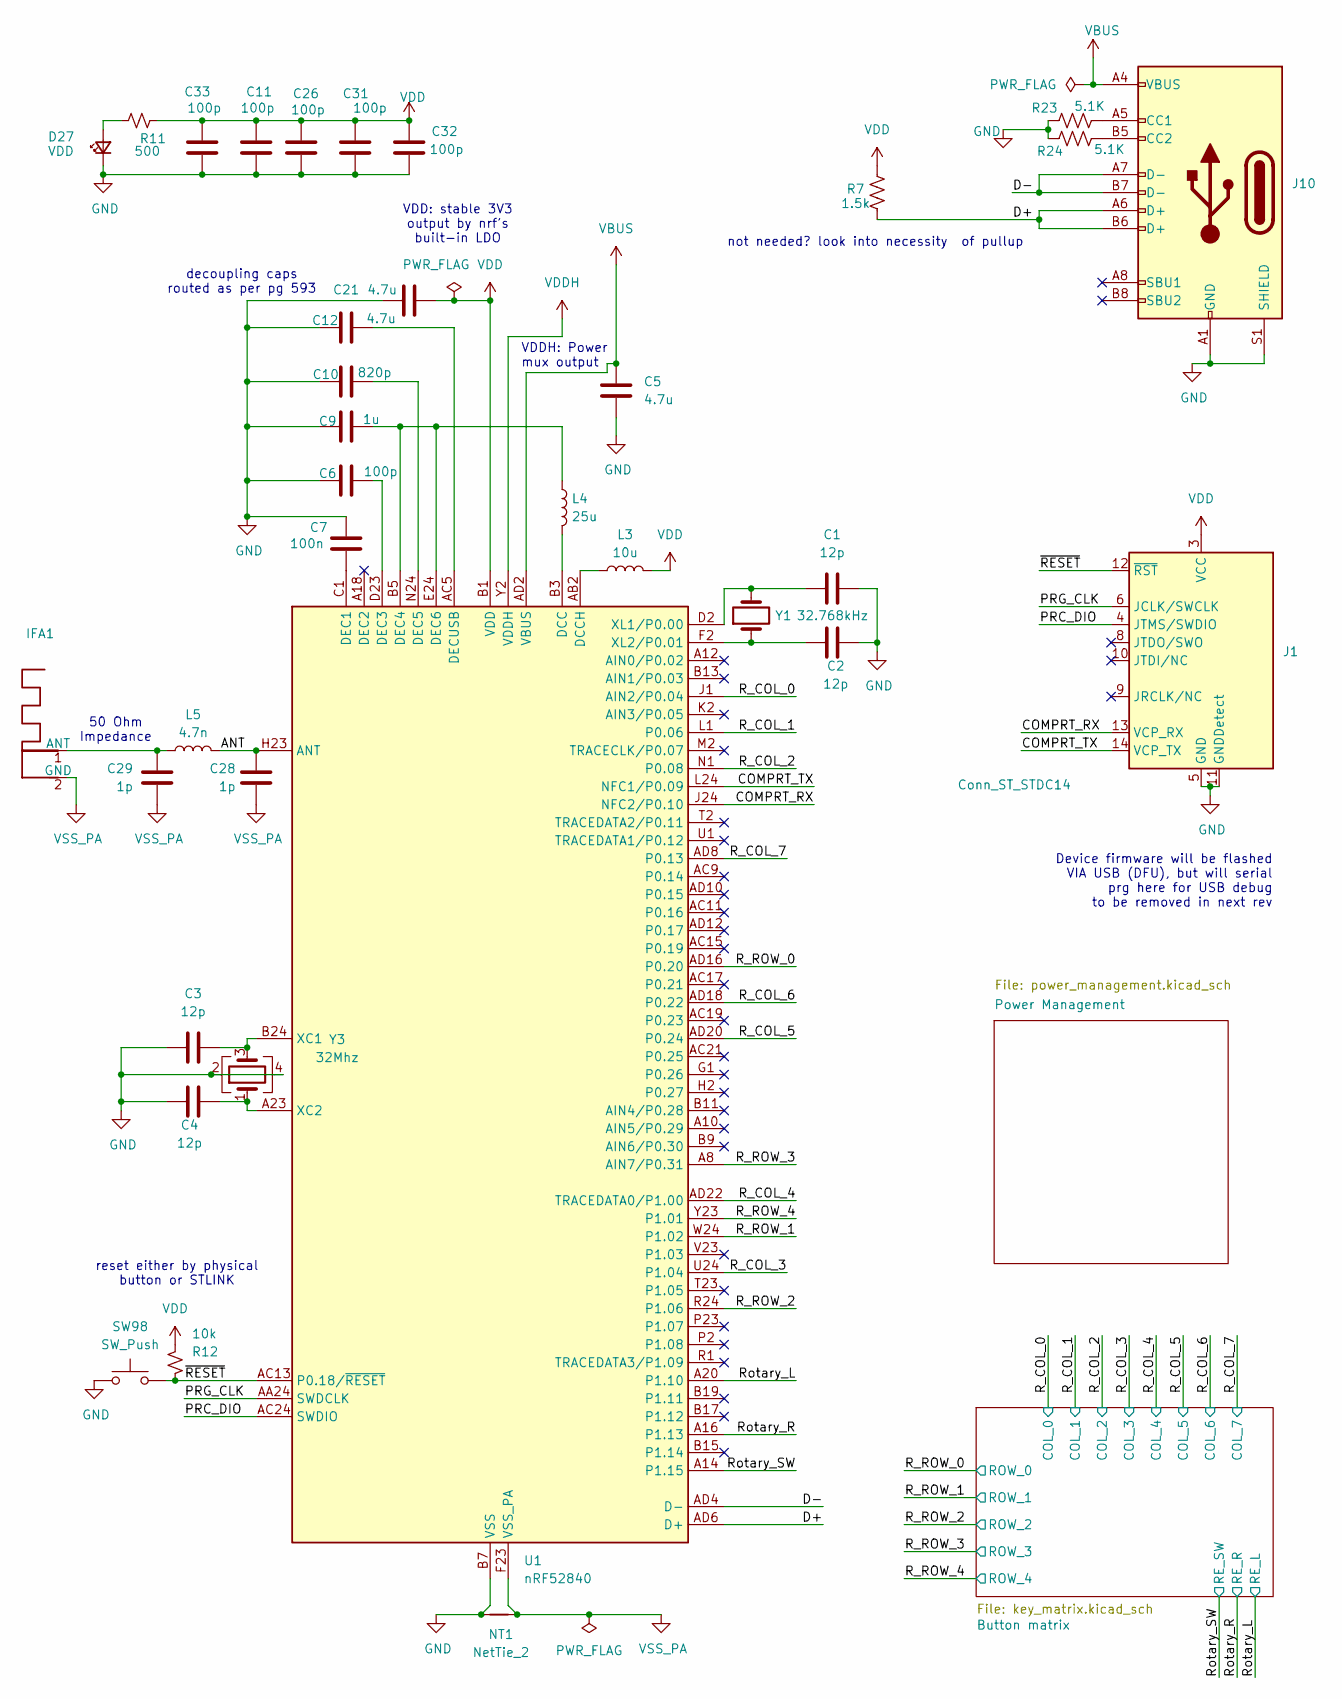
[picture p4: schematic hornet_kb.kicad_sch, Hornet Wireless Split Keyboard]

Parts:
C1, C2, C3, C4: 12p; C_0402_1005Metric; LCSC C1547
C5, C12, C21: 4.7u; C_0805_2012Metric; LCSC C1779
C6, C11, C26, C31, C32, C33: 100p; C_0603_1608Metric; LCSC C14858
C7: 100n; C_0603_1608Metric; LCSC C14663
C9: 1u; C_0603_1608Metric; LCSC C15849
C10: 820p; C_0603_1608Metric; LCSC C107057
C28, C29: 1p; C_0402_1005Metric; LCSC C1550
D27: VDD; LED_0402_1005Metric; LCSC C30584803
IFA1: Texas_SWRA117D_2.4GHz_Right
J1: Conn_ST_STDC14; Tag-Connect_TC2070-IDC-FP_2x07_P1.27mm_Vertical
J10: USB_C_Receptacle_USB2.0; USB_C_Receptacle_HRO_TYPE-C-31-M-12; LCSC C165948
L3: 10u; L_0402_1005Metric; LCSC C436512
L4: 25u; L_0402_1005Metric; LCSC C12669
L5: 4.7n; L_0402_1005Metric; LCSC C86065
NT1: NetTie_2; NetTie-2_SMD_Pad2.0mm
R7: 1.5k; R_0603_1608Metric; LCSC C22843
R11: 500; R_0603_1608Metric; LCSC C6207671
R12: 10k; R_0603_1608Metric; LCSC C25804
R23, R24: 5.1K; R_0603_1608Metric; LCSC C23186
SW98: SW_Push; SW_DIP_SPSTx01_Slide_6.7x4.1mm_W6.73mm_P2.54mm_LowProfile_J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; LCSC C720477
U1: nRF52840; Nordic_AQFN-73-1EP_7x7mm_P0.5mm; LCSC C190794
Y1: 32.768kHz; Crystal_SMD_3215-2Pin_3.2x1.5mm; LCSC C32346
Y3: 32Mhz; Crystal_SMD_2016-4Pin_2.0x1.6mm; LCSC C5339095

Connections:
/ANT: C28.1, L5.1, U1.H23 (ANT)
/COMPRT_RX: J1.13 (VCP_RX), U1.J24 (NFC2/P0.10)
/COMPRT_TX: J1.14 (VCP_TX), U1.L24 (NFC1/P0.09)
/D+: J10.A6 (D+), J10.B6 (D+), R7.2, U1.AD6 (D+)
/D-: J10.A7 (D-), J10.B7 (D-), U1.AD4 (D-)
/PRC_DIO: J1.4 (JTMS/SWDIO), U1.AC24 (SWDIO)
/PRG_CLK: J1.6 (JCLK/SWCLK), U1.AA24 (SWDCLK)
/R_COL_0: U1.J1 (AIN2/P0.04); also elsewhere on the board
/R_COL_1: U1.L1 (P0.06); also elsewhere on the board
/R_COL_2: U1.N1 (P0.08); also elsewhere on the board
/R_COL_3: U1.U24 (P1.04); also elsewhere on the board
/R_COL_4: U1.AD22 (TRACEDATA0/P1.00); also elsewhere on the board
/R_COL_5: U1.AD20 (P0.24); also elsewhere on the board
/R_COL_6: U1.AD18 (P0.22); also elsewhere on the board
/R_COL_7: U1.AD8 (P0.13); also elsewhere on the board
/R_ROW_0: U1.AD16 (P0.20); also elsewhere on the board
/R_ROW_1: U1.W24 (P1.02); also elsewhere on the board
/R_ROW_2: U1.R24 (P1.06); also elsewhere on the board
/R_ROW_3: U1.A8 (AIN7/P0.31); also elsewhere on the board
/R_ROW_4: U1.Y23 (P1.01); also elsewhere on the board
/Rotary_L: U1.A20 (P1.10); also elsewhere on the board
/Rotary_R: U1.A16 (P1.13); also elsewhere on the board
/Rotary_SW: U1.A14 (P1.15); also elsewhere on the board
/~RESET: J1.12 (~RST), R12.2, SW98.1, U1.AC13 (P0.18/~RESET)
GND: C1.1, C2.1, C3.1, C4.1, C5.2, C6.2, C7.2, C9.2, C10.1, C11.2, C12.2, C21.1, C26.2, C31.2, C32.2, C33.2, D27.1 (K), J1.5 (GND), J1.7 (GND), J1.11 (GNDDetect), J10.A1 (GND), J10.A12 (GND), J10.B1 (GND), J10.B12 (GND), J10.S1 (SHIELD), NT1.2, R23.1, R24.1, SW98.2, U1.B7 (VSS), U1.EP (VSS), Y3.2, Y3.4; also elsewhere on the board
unnamed: D27.2 (A), R11.2
unnamed: C29.1, IFA1.1 (ANT), L5.2
unnamed: J10.A5 (CC1), R23.2
unnamed: J10.B5 (CC2), R24.2
unnamed: L4.1, U1.B3 (DCC)
unnamed: L3.2, U1.AB2 (DCCH)
unnamed: C7.1, U1.C1 (DEC1)
unnamed: C6.1, U1.D23 (DEC3)
unnamed: C9.1, L4.2, U1.B5 (DEC4), U1.E24 (DEC6)
unnamed: C10.2, U1.N24 (DEC5)
unnamed: C12.1, U1.AC5 (DECUSB)
unnamed: C3.2, U1.B24 (XC1), Y3.3
unnamed: C4.2, U1.A23 (XC2), Y3.1
unnamed: C1.2, U1.D2 (XL1/P0.00), Y1.2
unnamed: C2.2, U1.F2 (XL2/P0.01), Y1.1
VBUS: C5.1, J10.A4 (VBUS), J10.A9 (VBUS), J10.B4 (VBUS), J10.B9 (VBUS), U1.AD2 (VBUS); also elsewhere on the board
VDD: C11.1, C21.2, C26.1, C31.1, C32.1, C33.1, J1.3 (VCC), L3.1, R7.1, R11.1, R12.1, U1.A22 (VDD), U1.AD14 (VDD), U1.AD23 (VDD), U1.B1 (VDD), U1.W1 (VDD); also elsewhere on the board
VDDH: U1.Y2 (VDDH); also elsewhere on the board
VSS_PA: C28.2, C29.2, IFA1.2 (GND), NT1.1, U1.F23 (VSS_PA)

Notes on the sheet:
VDDH: Power mux output
50 Ohm Impedance
Device firmware will be flashed VIA USB (DFU), but will serial prg here for USB debug to be removed in next rev
decoupling caps routed as per pg 593
VDD: stable 3V3 output by nrf's built-in LDO
reset either by physical button or STLINK
not needed? look into necessity of pullup

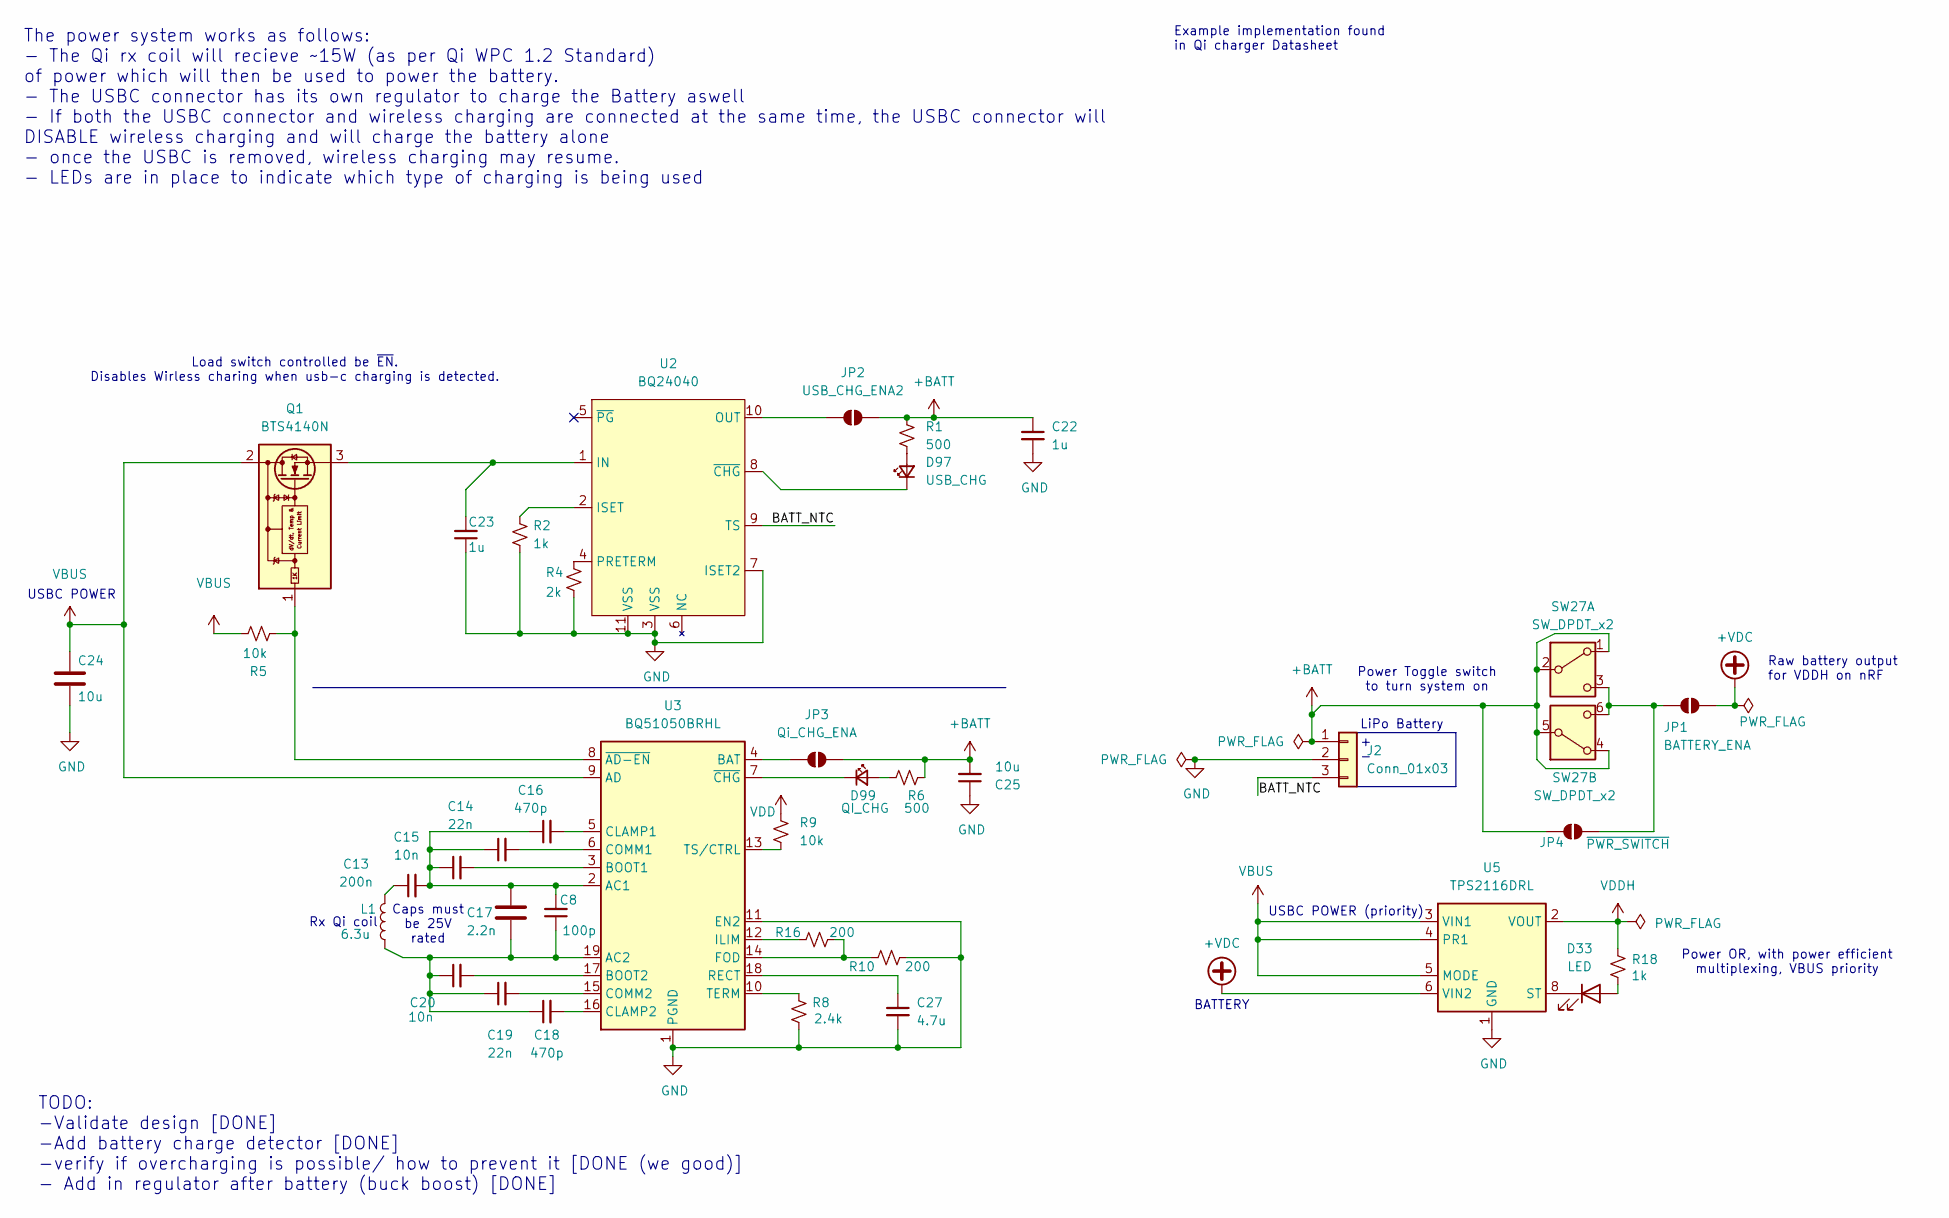
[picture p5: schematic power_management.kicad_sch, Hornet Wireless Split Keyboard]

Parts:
C8: 100p; C_0603_1608Metric; LCSC C14858
C13: 200n; C_0603_1608Metric; LCSC C1002
C14, C19: 22n; C_0603_1608Metric; LCSC C21122
C15, C20: 10n; C_0603_1608Metric; LCSC C57112
C16, C18: 470p; C_0603_1608Metric; LCSC C1620
C17: 2.2n; C_0603_1608Metric; LCSC C1604
C22, C23: 1u; C_0603_1608Metric; LCSC C15849
C24, C25: 10u; C_0603_1608Metric; LCSC C19702
C27: 4.7u; C_0603_1608Metric; LCSC C19666
D33: LED; LED_0402_1005Metric; LCSC C28310436
D97: USB_CHG; LED_0402_1005Metric; LCSC C20608784
D99: QI_CHG; LED_0402_1005Metric; LCSC C20608784
J2: Conn_01x03; JST_GH_SM03B-GHS-TB_1x03-1MP_P1.25mm_Horizontal; LCSC C514175
JP1: BATTERY_ENA; SolderJumper-2_P1.3mm_Open_TrianglePad1.0x1.5mm
JP2: USB_CHG_ENA2; SolderJumper-2_P1.3mm_Open_TrianglePad1.0x1.5mm
JP3: Qi_CHG_ENA; SolderJumper-2_P1.3mm_Open_TrianglePad1.0x1.5mm
JP4: ~{PWR_SWITCH}; SolderJumper-2_P1.3mm_Open_TrianglePad1.0x1.5mm
L1: 6.3u; TerminalBlock_Phoenix_MKDS-1,5-2-5.08_1x02_P5.08mm_Horizont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; LCSC C8465
Q1: BTS4140N; SOT-223; LCSC C59442
R1, R6: 500; R_0603_1608Metric; LCSC C6207671
R2, R18: 1k; R_0603_1608Metric; LCSC C21190
R4: 2k; R_0603_1608Metric; LCSC C22975
R5, R9: 10k; R_0603_1608Metric; LCSC C25804
R8: 2.4k; R_0603_1608Metric; LCSC C22940
R10, R16: 200; R_0603_1608Metric; LCSC C8218
SW27: SW_DPDT_x2; SW_CK_JS202011CQN_DPDT_Straight; LCSC C1788494
U2: BQ24040; Texas_DLH0010A_WSON-10-1EP_2.2x2mm_P0.4mm_EP0.9x1.5mm_Therm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; LCSC C2876332
U3: BQ51050BRHL; Texas_VQFN-RHL-20; LCSC C133307
U5: TPS2116DRL; SOT-583-8; LCSC C3235557

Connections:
+BATT: C22.1, C25.2, J2.1, JP2.2 (B), JP3.2 (B), JP4.1 (A), R1.1, R6.1, SW27.1 (A), SW27.2 (B), SW27.4 (A), SW27.5 (B)
+VDC: JP1.2 (B), U5.6 (VIN2)
/Power Management/BATT_NTC: J2.3, U2.9 (TS)
GND: C22.2, C23.1, C24.2, C25.1, C27.2, J2.2, R2.1, R4.1, R8.2, R10.2, U2.3 (VSS), U2.7 (ISET2), U2.11 (VSS), U3.1 (PGND), U3.11 (EN2), U3.20 (PGND), U3.21 (PGND), U5.1 (GND); also elsewhere on the board
unnamed: C13.1, L1.2
unnamed: D33.2 (A), R18.1
unnamed: D33.1 (K), U5.8 (ST)
unnamed: D97.2 (A), R1.2
unnamed: D97.1 (K), U2.8 (~CHG)
unnamed: D99.2 (A), R6.2
unnamed: D99.1 (K), U3.7 (~CHG)
unnamed: JP1.1 (A), JP4.2 (B), SW27.3 (C), SW27.6 (C)
unnamed: JP2.1 (A), U2.10 (OUT)
unnamed: JP3.1 (A), U3.4 (BAT)
unnamed: Q1.1 (IN), R5.1, U3.8 (~AD-EN)
unnamed: C23.2, Q1.3 (OUT), U2.1 (IN)
unnamed: R2.2, U2.2 (ISET)
unnamed: R4.2, U2.4 (PRETERM)
unnamed: C8.2, C13.2, C14.1, C15.1, C16.1, C17.1, U3.2 (AC1)
unnamed: C8.1, C17.2, C18.1, C19.1, C20.1, L1.1, U3.19 (AC2)
unnamed: C15.2, U3.3 (BOOT1)
unnamed: C20.2, U3.17 (BOOT2)
unnamed: C16.2, U3.5 (CLAMP1)
unnamed: C18.2, U3.16 (CLAMP2)
unnamed: C14.2, U3.6 (COMM1)
unnamed: C19.2, U3.15 (COMM2)
unnamed: R10.1, R16.2, U3.14 (FOD)
unnamed: R16.1, U3.12 (ILIM)
unnamed: C27.1, U3.18 (RECT)
unnamed: R8.1, U3.10 (TERM)
unnamed: R9.2, U3.13 (TS/CTRL)
VBUS: C24.1, Q1.2 (V_{bb}), Q1.4 (V_{bb}), R5.2, U3.9 (AD), U5.3 (VIN1), U5.4 (PR1), U5.5 (MODE); also elsewhere on the board
VDD: R9.1; also elsewhere on the board
VDDH: R18.2, U5.2 (VOUT), U5.7 (VOUT); also elsewhere on the board

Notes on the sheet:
Power OR, with power efficient multiplexing, VBUS priority
Rx Qi coil
The power system works as follows: - The Qi rx coil will recieve ~15W (as per Qi WPC 1.2 Standard) of power which will then be used to power the battery. - The USBC connector has its own regulator to charge the Battery aswell - If both the USBC connector and wireless charging are connected at the s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
Raw battery output for VDDH on nRF
USBC POWER (priority)
USBC POWER
LiPo Battery
Example implementation found in Qi charger Datasheet
BATTERY
Caps must be 25V rated
Load switch controlled be ~{EN}. Disables Wirless charing when usb-c charging is detected.
Power Toggle switch to turn system on
+ -
TODO: -Validate design [DONE] -Add battery charge detector [DONE] -verify if overcharging is possible/ how to prevent it [DONE (we good)] - Add in regulator after battery (buck boost) [DONE]

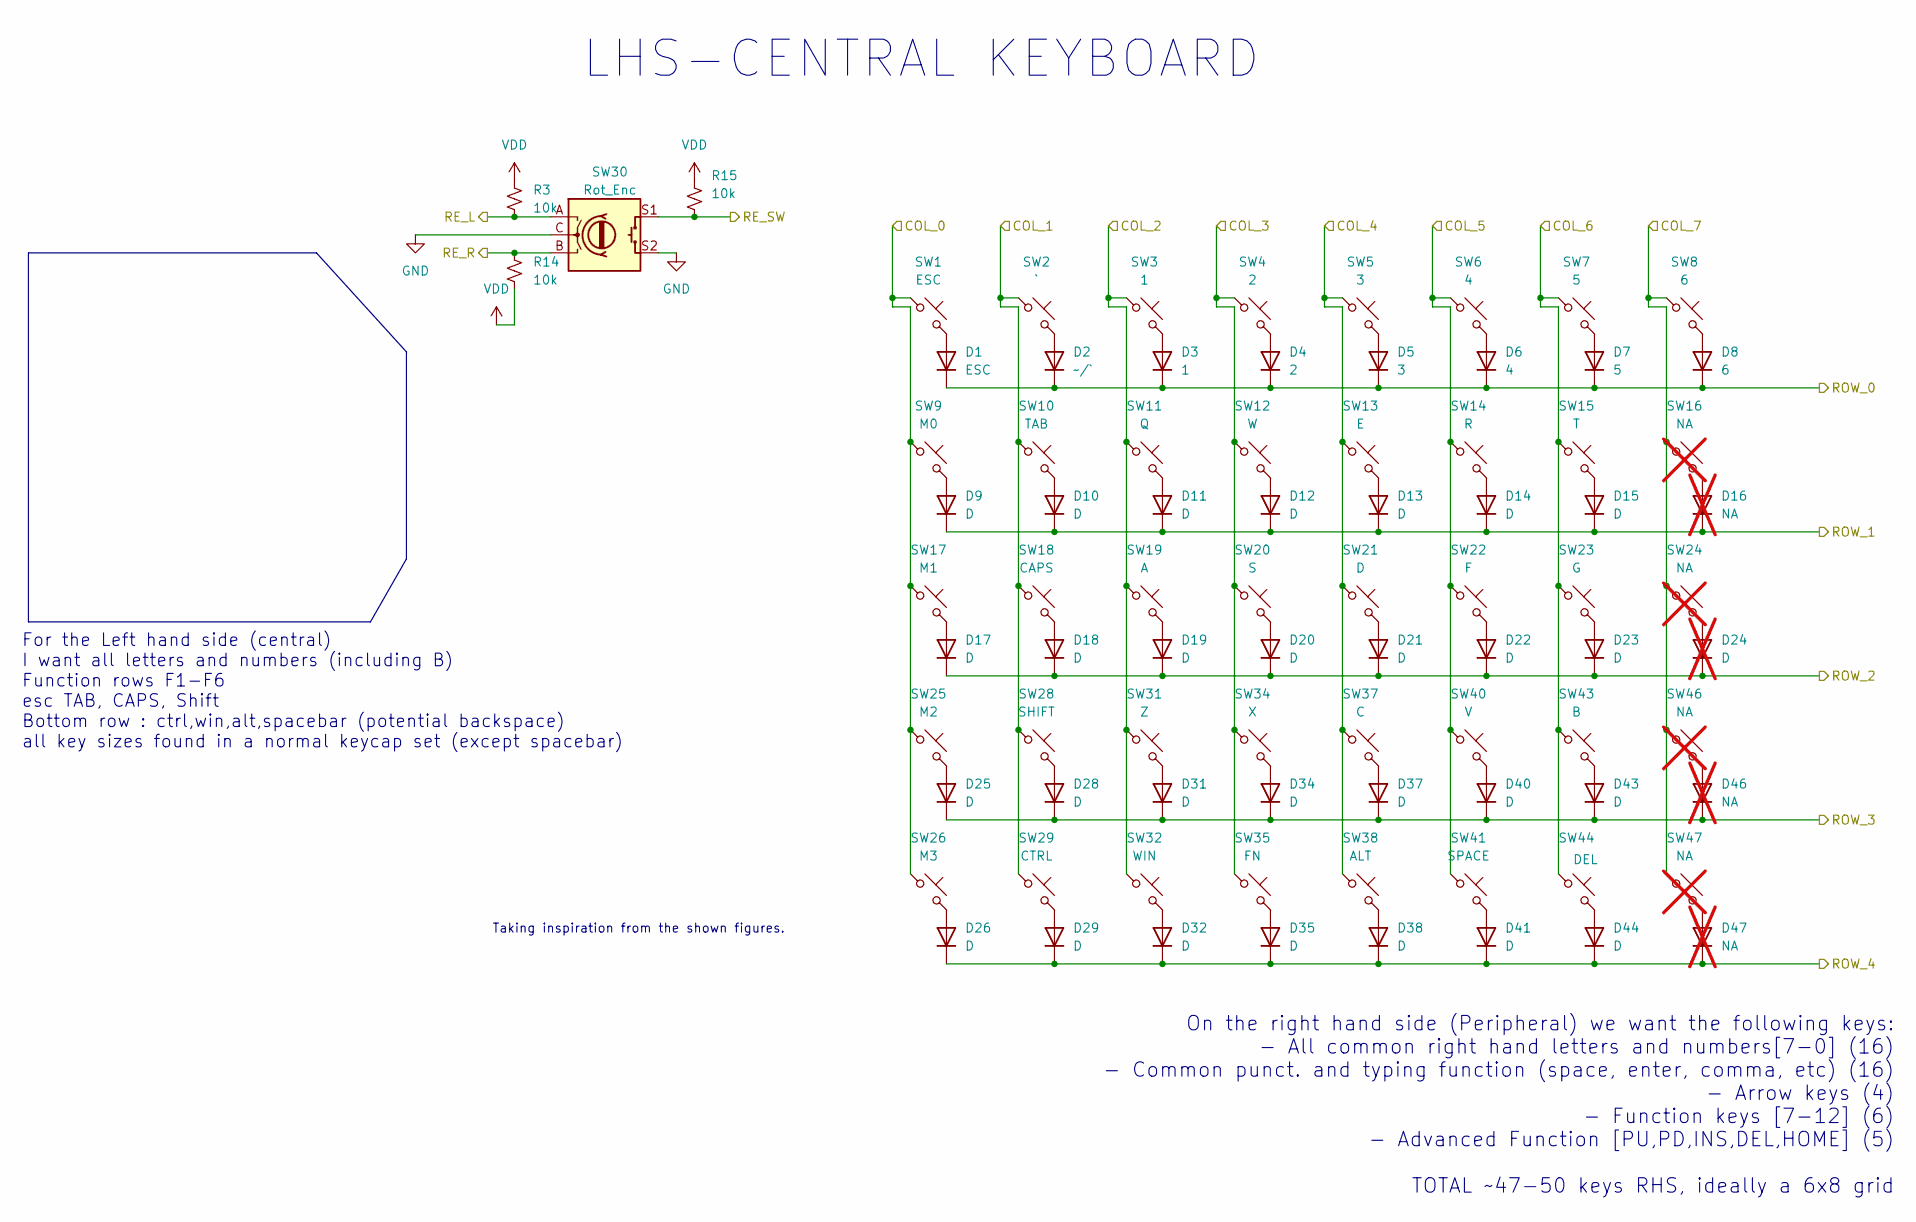
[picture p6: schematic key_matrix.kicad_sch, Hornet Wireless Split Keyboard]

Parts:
D1: ESC; Diode_SOD-123; LCSC C917030
D2: ~/`; Diode_SOD-123; LCSC C917030
D3: 1; Diode_SOD-123; LCSC C917030
D4: 2; Diode_SOD-123; LCSC C917030
D5: 3; Diode_SOD-123; LCSC C917030
D6: 4; Diode_SOD-123; LCSC C917030
D7: 5; Diode_SOD-123; LCSC C917030
D8: 6; Diode_SOD-123; LCSC C917030
D9, D10, D11, D12, D13, D14, D15, D17, D18, D19, D20, D21, D22, D23, D25, D26, D28, D29, D31, D32, D34, D35, D37, D38, D40, D41, D43, D44: D; Diode_SOD-123; LCSC C917030
D16, D46, D47: NA; Diode_SOD-123; not fitted
D24: D; Diode_SOD-123; not fitted
R3, R14, R15: 10k; R_0603_1608Metric; LCSC C25804
SW1: ESC; Hotswap_MX_1.00u; LCSC C41430893
SW2: `; Hotswap_MX_1.00u; LCSC C41430893
SW3: 1; Hotswap_MX_1.00u; LCSC C41430893
SW4: 2; Hotswap_MX_1.00u; LCSC C41430893
SW5: 3; Hotswap_MX_1.00u; LCSC C41430893
SW6: 4; Hotswap_MX_1.00u; LCSC C41430893
SW7: 5; Hotswap_MX_1.00u; LCSC C41430893
SW8: 6; Hotswap_MX_1.00u; LCSC C41430893
SW9: M0; Hotswap_MX_1.00u; LCSC C41430893
SW10: TAB; Hotswap_MX_1.50u; LCSC C41430893
SW11: Q; Hotswap_MX_1.00u; LCSC C41430893
SW12: W; Hotswap_MX_1.00u; LCSC C41430893
SW13: E; Hotswap_MX_1.00u; LCSC C41430893
SW14: R; Hotswap_MX_1.00u; LCSC C41430893
SW15: T; Hotswap_MX_1.00u; LCSC C41430893
SW16: NA; Hotswap_MX_1.00u; not fitted
SW17: M1; Hotswap_MX_1.00u; LCSC C41430893
SW18: CAPS; Hotswap_MX_1.75u; LCSC C41430893
SW19: A; Hotswap_MX_1.00u; LCSC C41430893
SW20: S; Hotswap_MX_1.00u; LCSC C41430893
SW21: D; Hotswap_MX_1.00u; LCSC C41430893
SW22: F; Hotswap_MX_1.00u; LCSC C41430893
SW23: G; Hotswap_MX_1.00u; LCSC C41430893
SW24: NA; Hotswap_MX_1.50u; not fitted
SW25: M2; Hotswap_MX_1.00u; LCSC C41430893
SW26: M3; Hotswap_MX_1.00u; LCSC C41430893
SW28: SHIFT; Hotswap_MX_2.25u; LCSC C41430893
SW29: CTRL; Hotswap_MX_1.25u; LCSC C41430893
SW30: Rot_Enc; RotaryEncoder_Alps_EC11E-Switch_Vertical_H20mm; LCSC C41430893
SW31: Z; Hotswap_MX_1.00u; LCSC C41430893
SW32: WIN; Hotswap_MX_1.00u; LCSC C41430893
SW34: X; Hotswap_MX_1.00u; LCSC C41430893
SW35: FN; Hotswap_MX_1.25u; LCSC C41430893
SW37: C; Hotswap_MX_1.00u; LCSC C41430893
SW38: ALT; Hotswap_MX_1.25u; LCSC C41430893
SW40: V; Hotswap_MX_1.00u; LCSC C41430893
SW41: SPACE; Hotswap_MX_2.25u; LCSC C41430893
SW43: B; Hotswap_MX_1.00u; LCSC C41430893
SW44: DEL; Hotswap_MX_1.00u; LCSC C41430893
SW46, SW47: NA; not fitted

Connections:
/R_COL_0: SW1.1, SW9.1, SW17.1, SW25.1, SW26.1; also elsewhere on the board
/R_COL_1: SW2.1, SW10.1, SW18.1, SW28.1, SW29.1; also elsewhere on the board
/R_COL_2: SW3.1, SW11.1, SW19.1, SW31.1, SW32.1; also elsewhere on the board
/R_COL_3: SW4.1, SW12.1, SW20.1, SW34.1, SW35.1; also elsewhere on the board
/R_COL_4: SW5.1, SW13.1, SW21.1, SW37.1, SW38.1; also elsewhere on the board
/R_COL_5: SW6.1, SW14.1, SW22.1, SW40.1, SW41.1; also elsewhere on the board
/R_COL_6: SW7.1, SW15.1, SW23.1, SW43.1, SW44.1; also elsewhere on the board
/R_COL_7: SW8.1, SW16.1, SW24.1, SW46.1, SW47.1; also elsewhere on the board
/R_ROW_0: D1.1 (K), D2.1 (K), D3.1 (K), D4.1 (K), D5.1 (K), D6.1 (K), D7.1 (K), D8.1 (K); also elsewhere on the board
/R_ROW_1: D9.1 (K), D10.1 (K), D11.1 (K), D12.1 (K), D13.1 (K), D14.1 (K), D15.1 (K), D16.1 (K); also elsewhere on the board
/R_ROW_2: D17.1 (K), D18.1 (K), D19.1 (K), D20.1 (K), D21.1 (K), D22.1 (K), D23.1 (K), D24.1 (K); also elsewhere on the board
/R_ROW_3: D25.1 (K), D28.1 (K), D31.1 (K), D34.1 (K), D37.1 (K), D40.1 (K), D43.1 (K), D46.1 (K); also elsewhere on the board
/R_ROW_4: D26.1 (K), D29.1 (K), D32.1 (K), D35.1 (K), D38.1 (K), D41.1 (K), D44.1 (K), D47.1 (K); also elsewhere on the board
/Rotary_L: R3.1, SW30.A; also elsewhere on the board
/Rotary_R: R14.2, SW30.B; also elsewhere on the board
/Rotary_SW: R15.1, SW30.S1; also elsewhere on the board
GND: SW30.C, SW30.S2; also elsewhere on the board
unnamed: D1.2 (A), SW1.2
unnamed: D2.2 (A), SW2.2
unnamed: D3.2 (A), SW3.2
unnamed: D4.2 (A), SW4.2
unnamed: D5.2 (A), SW5.2
unnamed: D6.2 (A), SW6.2
unnamed: D7.2 (A), SW7.2
unnamed: D8.2 (A), SW8.2
unnamed: D9.2 (A), SW9.2
unnamed: D10.2 (A), SW10.2
unnamed: D11.2 (A), SW11.2
unnamed: D12.2 (A), SW12.2
unnamed: D13.2 (A), SW13.2
unnamed: D14.2 (A), SW14.2
unnamed: D15.2 (A), SW15.2
unnamed: D16.2 (A), SW16.2
unnamed: D17.2 (A), SW17.2
unnamed: D18.2 (A), SW18.2
unnamed: D19.2 (A), SW19.2
unnamed: D20.2 (A), SW20.2
unnamed: D21.2 (A), SW21.2
unnamed: D22.2 (A), SW22.2
unnamed: D23.2 (A), SW23.2
unnamed: D24.2 (A), SW24.2
unnamed: D25.2 (A), SW25.2
unnamed: D26.2 (A), SW26.2
unnamed: D28.2 (A), SW28.2
unnamed: D29.2 (A), SW29.2
unnamed: D31.2 (A), SW31.2
unnamed: D32.2 (A), SW32.2
unnamed: D34.2 (A), SW34.2
unnamed: D35.2 (A), SW35.2
unnamed: D37.2 (A), SW37.2
unnamed: D38.2 (A), SW38.2
unnamed: D40.2 (A), SW40.2
unnamed: D41.2 (A), SW41.2
unnamed: D43.2 (A), SW43.2
unnamed: D44.2 (A), SW44.2
unnamed: D46.2 (A), SW46.2
unnamed: D47.2 (A), SW47.2
VDD: R3.2, R14.1, R15.2; also elsewhere on the board

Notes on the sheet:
For the Left hand side (central) I want all letters and numbers (including B) Function rows F1-F6 esc TAB, CAPS, Shift Bottom row : ctrl,win,alt,spacebar (potential backspace) all key sizes found in a normal keycap set (except spacebar)
On the right hand side (Peripheral) we want the following keys: - All common right hand letters and numbers[7-0] (16) - Common punct. and typing function (space, enter, comma, etc) (16) - Arrow keys (4) - Function keys [7-12] (6) - Advanced Function [PU,PD,INS,DEL,HOME] (5) TOTAL ~47-50 keys RHS, i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
LHS-CENTRAL KEYBOARD
Taking inspiration from the shown figures.

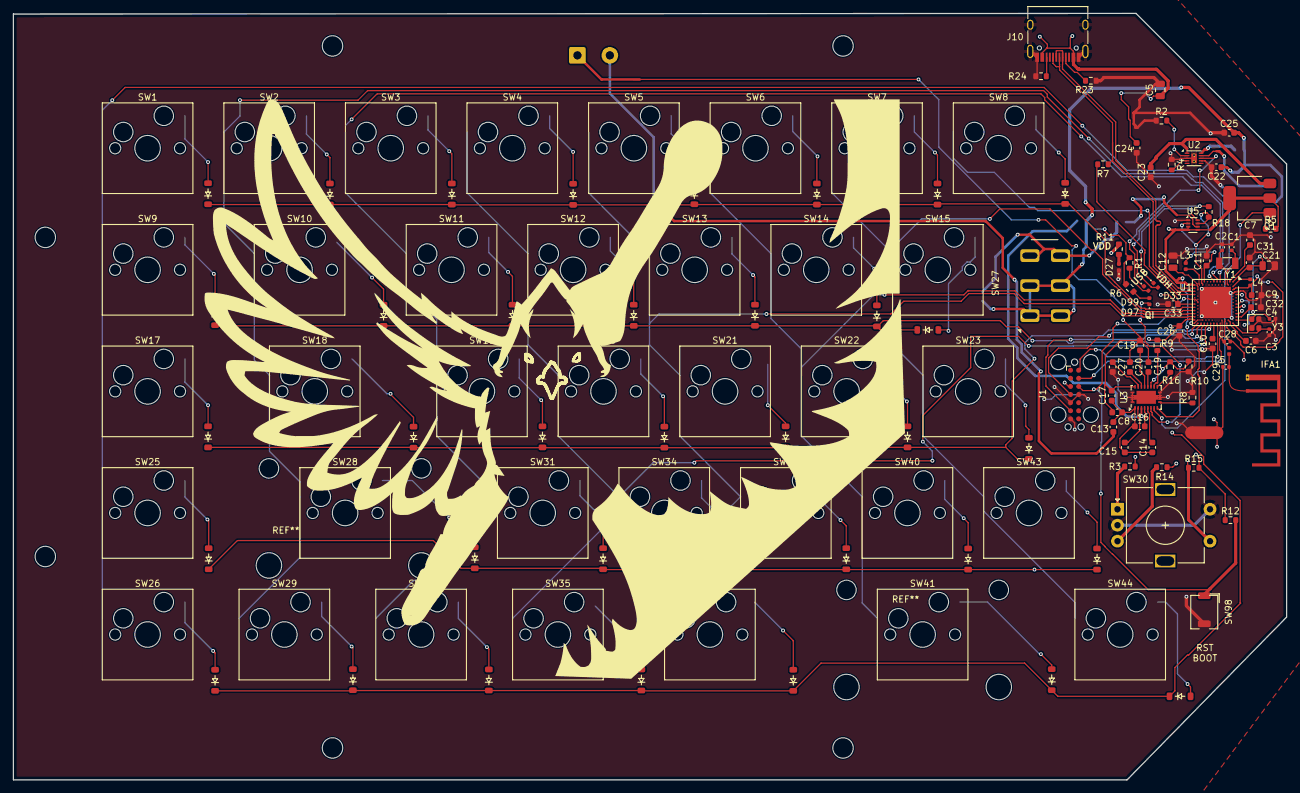
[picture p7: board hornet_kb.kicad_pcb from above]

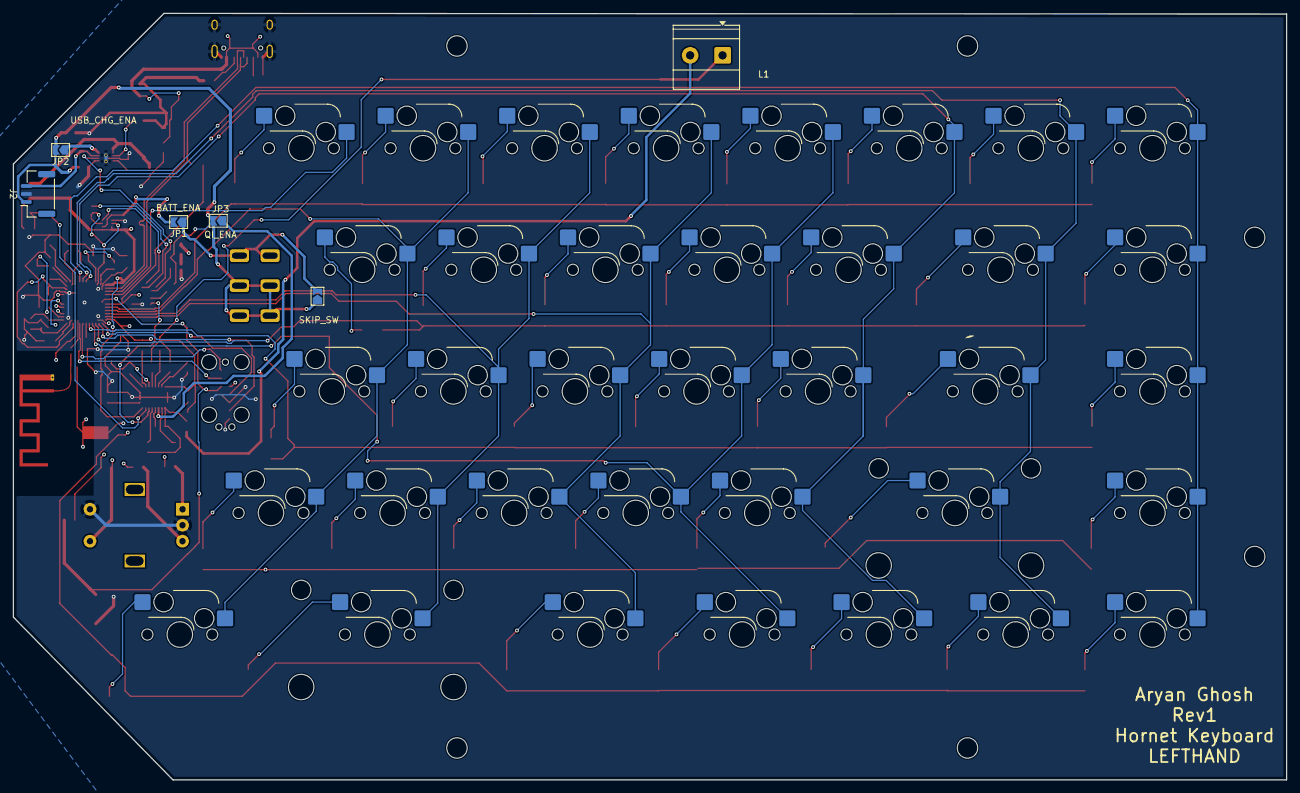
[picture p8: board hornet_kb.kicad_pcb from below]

Board: 4 copper layers, 199.5 x 120.1 mm, 149 parts (6 on the bottom side), 110 nets.

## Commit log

2025-10-25 Resolving DRC errors
    [hornet_kb.kicad_pcb, hornet_kb.kicad_sch]
2025-10-25 Change reset switchto custom footprint
    [hornet_kb.kicad_pcb, hornet_kb.kicad_sch]
2025-10-25 added mounting holes
    [hornet_kb.kicad_pcb, hornet_kb.kicad_sch, key_matrix.kicad_sch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]
2025-10-25 ADded cardinal
    [hornet_kb.kicad_pcb]
2025-10-26 Add LCSC part numbers and new resistor to PCB
    Added LCSC part numbers to multiple components in hornet_kb.kicad_pcb for improved BOM generation. Introduced a new 500Ω resistor (R11) and updated net assignments for Q1 and D27. Modified .gitignore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
    [hornet_kb.kicad_pcb, hornet_kb.kicad_sch, key_matrix.kicad_sch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]
2025-10-26 Added LCSC part defs
    [hornet_kb.kicad_pcb, hornet_kb.kicad_sch, key_matrix.kicad_sch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]
2025-10-26 Final Commits before production
    [hornet_kb.kicad_pcb]
2025-10-26 Revise README for Hornet Keyboard project
    Updated README to provide detailed project overview, features, schematics, layout, system architecture, design challenges, tools, firmware architecture, and key learning outcomes.
2025-11-07 Add mechanical files for case and plate
    [BOM-hornet_kb-JLCPCB Assembly Orderfromjlc.xls, CaseV1.SLDPRT, CaseV1_print1.STEP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]
2025-11-08 Small adjustments
    [CaseV1.SLDPRT, hornet_kb.kicad_pcb]
